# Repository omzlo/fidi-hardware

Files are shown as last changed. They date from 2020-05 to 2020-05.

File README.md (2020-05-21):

# FIDI 

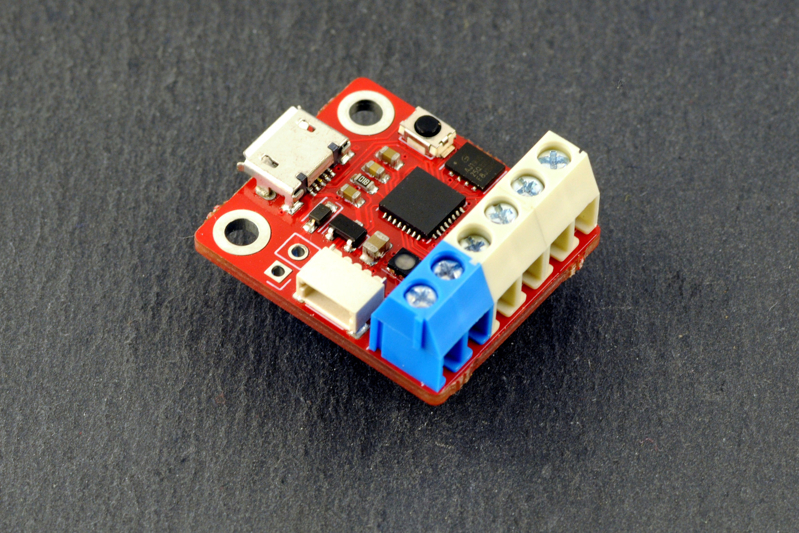
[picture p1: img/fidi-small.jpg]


FIDI is a small development board running Adafruit's CircuitPython, featuring 6 terminal block connectors and a qwiic connector, designed for fast prototyping. It runs on the ATSAMD21 microcontroller, a 32-bit Arm Cortex M0+ clocked at 48Mhz, as found on many popular Arduino-compatible boards.

For more info, see https://www.omzlo.com/fidi

# Acknowledgement 

This design borrows largely from SERPENTE, by Arturo182 (https://github.com/arturo182/serpente_hw).

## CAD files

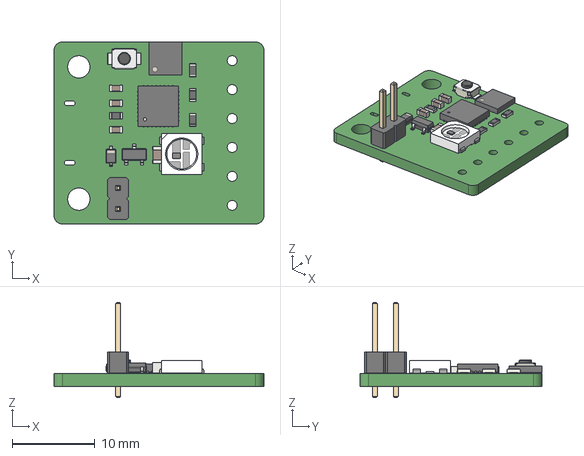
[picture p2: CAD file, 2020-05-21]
fidi-micro.step
25.4 x 22.0 x 11.5 mm

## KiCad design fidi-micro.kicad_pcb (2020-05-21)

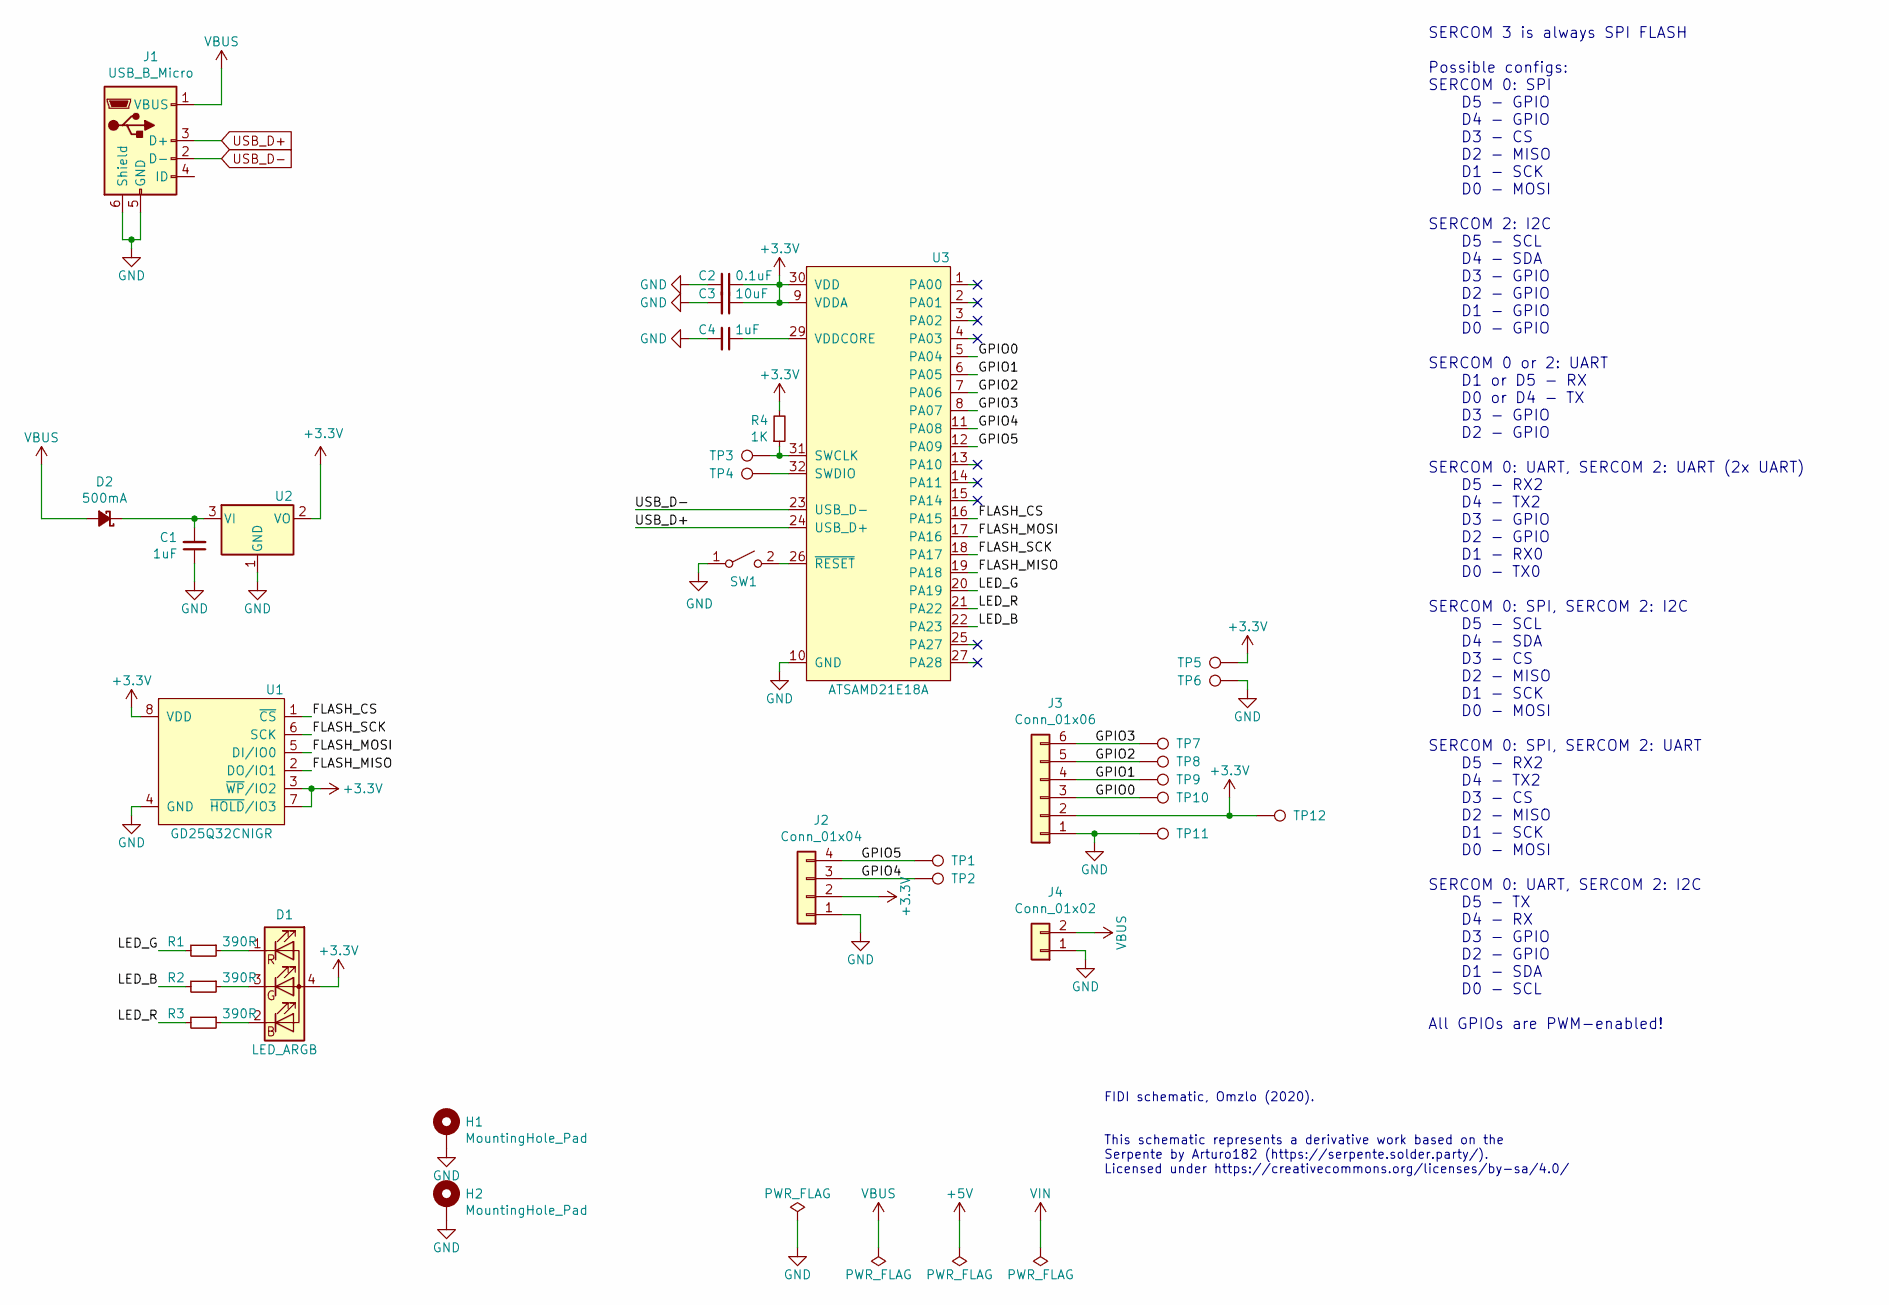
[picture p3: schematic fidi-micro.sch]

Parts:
C1, C4: 1uF; C_0603_1608Metric
C2: 0.1uF; C_0603_1608Metric
C3: 10uF; C_0805_2012Metric
D1: LED_ARGB; LED_Cree-PLCC4_2x2mm_CW
D2: 500mA; D_SOD-323_HandSoldering
H1, H2: MountingHole_Pad; MountingHole_2.7mm_M2.5_DIN965_Pad
J1: USB_B_Micro; USB_Micro-B_LCSC_C40951
J2: Conn_01x04; JST_SH_SM04B-SRSS-TB_1x04-1MP_P1.00mm_Horizontal
J3: Conn_01x06; TerminalBlock_4Ucon_1x06_P3.50mm_Horizontal
J4: Conn_01x02; PinHeader_1x02_P2.54mm_Vertical
R1, R2, R3: 390R; R_0603_1608Metric
R4: 1K; R_0603_1608Metric
SW1: SW_RESET; SW_SPST_B3U-1000P
TP1, TP2, TP4, TP7, TP8, TP9, TP10, TP11, TP12: TP_SWDIO; TestPoint_Pad_D1.0mm
TP3: TP_SWCLK; TestPoint_Pad_D1.0mm
TP5: TP_VDD; TestPoint_Pad_D1.0mm
TP6: TP_GND; TestPoint_Pad_D1.0mm
U1: GD25Q32CNIGR; USON-8_3x4mm_P0.8mm
U2: MCP1700-3302E_SOT23; SOT-23
U3: ATSAMD21E18A; QFN-32-1EP_5x5mm_P0.5mm_EP3.6x3.6mm

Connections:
+3V3: C2.1, C3.1, D1.4 (A), J2.2, J3.2, R4.2, TP5.1, TP12.1, U1.3 (~WP~/IO2), U1.7 (~HOLD~/IO3), U1.8 (VDD), U2.2 (VO), U3.9 (VDDA), U3.30 (VDD)
/FLASH_CS: U1.1 (~CS~), U3.16 (PA15)
/FLASH_MISO: U1.2 (DO/IO1), U3.19 (PA18)
/FLASH_MOSI: U1.5 (DI/IO0), U3.17 (PA16)
/FLASH_SCK: U1.6 (SCK), U3.18 (PA17)
/GPIO0: J3.3, TP10.1, U3.5 (PA04)
/GPIO1: J3.4, TP9.1, U3.6 (PA05)
/GPIO2: J3.5, TP8.1, U3.7 (PA06)
/GPIO3: J3.6, TP7.1, U3.8 (PA07)
/GPIO4: J2.3, TP2.1, U3.11 (PA08)
/GPIO5: J2.4, TP1.1, U3.12 (PA09)
/LED_B: R2.2, U3.22 (PA23)
/LED_G: R1.2, U3.20 (PA19)
/LED_R: R3.2, U3.21 (PA22)
GND: C1.1, C2.2, C3.2, C4.2, H1.1, H2.1, J1.5 (GND), J1.6 (Shield), J2.1, J3.1, J4.1, SW1.1 (A), TP6.1, TP11.1, U1.4 (GND), U2.1 (GND), U3.10 (GND), U3.28 (GND)
unnamed: C1.2, D2.1 (K), U2.3 (VI)
unnamed: C4.1, U3.29 (VDDCORE)
unnamed: D1.1 (RK), R1.1
unnamed: D1.2 (BK), R3.1
unnamed: D1.3 (GK), R2.1
unnamed: R4.1, TP3.1, U3.31 (SWCLK)
unnamed: SW1.2 (B), U3.26 (~RESET~)
unnamed: TP4.1, U3.32 (SWDIO)
USB_D+: J1.3 (D+), U3.24 (USB_D+)
USB_D-: J1.2 (D-), U3.23 (USB_D-)
VBUS: D2.2 (A), J1.1 (VBUS), J4.2

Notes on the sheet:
SERCOM 3 is always SPI FLASH Possible configs: SERCOM 0: SPI D5 - GPIO D4 - GPIO D3 - CS D2 - MISO D1 - SCK D0 - MOSI SERCOM 2: I2C D5 - SCL D4 - SDA D3 - GPIO D2 - GPIO D1 - GPIO D0 - GPIO SERCOM 0 or 2: UART D1 or D5 - RX D0 or D4 - TX D3 - GPIO D2 - GPIO SERCOM 0: UART, SERCOM 2: UART (2x UART) 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
This schematic represents a derivative work based on the Serpente by Arturo182 (https://serpente.solder.party/). Licensed under https://creativecommons.org/licenses/by-sa/4.0/
FIDI schematic, Omzlo (2020).

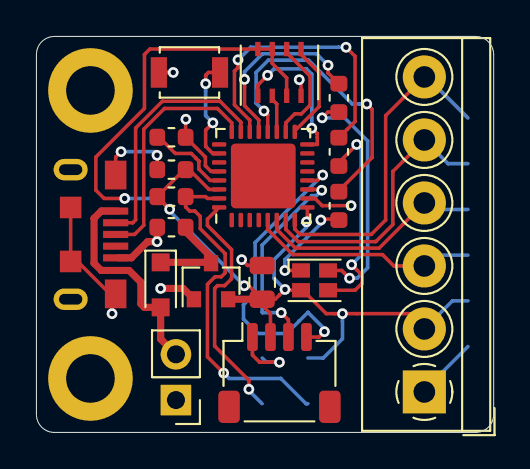
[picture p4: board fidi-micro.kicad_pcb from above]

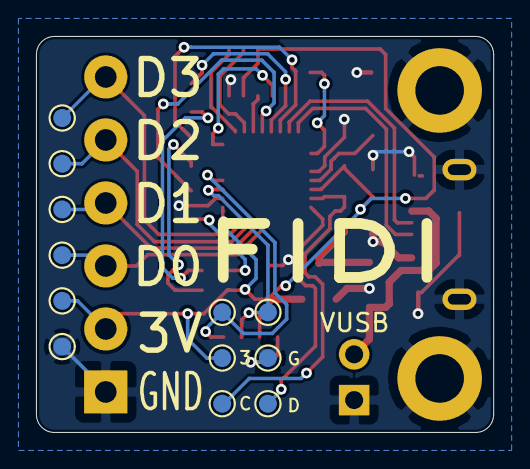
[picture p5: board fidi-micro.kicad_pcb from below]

Board: 2 copper layers, 25.4 x 22.0 mm, 32 parts (12 on the bottom side), 26 nets.
